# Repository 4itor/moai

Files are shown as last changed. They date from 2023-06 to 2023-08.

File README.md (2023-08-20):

# moai Keyboard

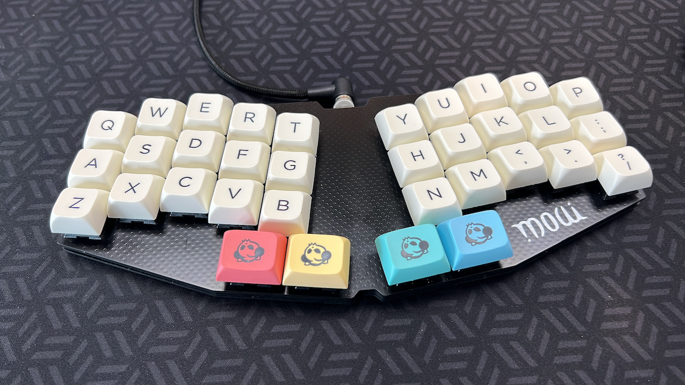
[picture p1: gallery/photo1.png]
Moai


A small, 34 key, low(ish) profile keyboard with MX switches.

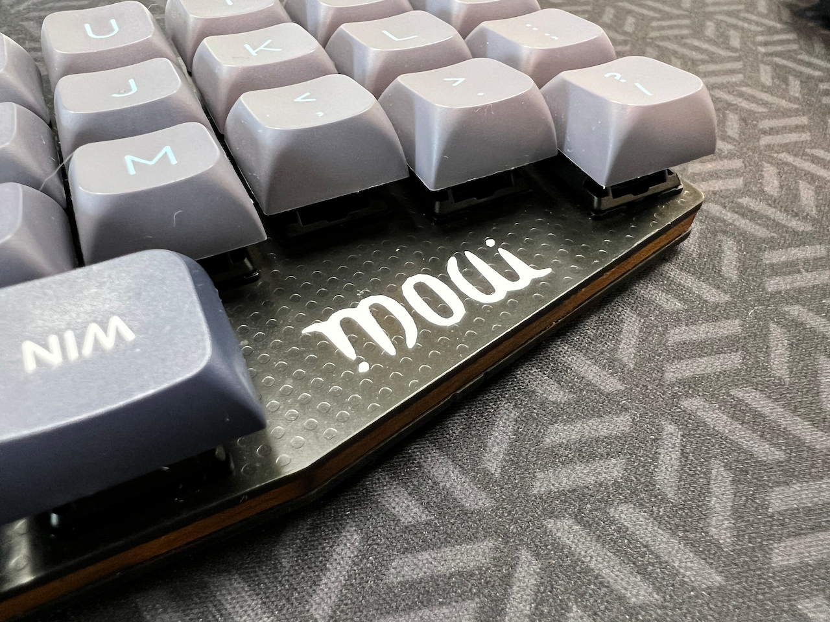
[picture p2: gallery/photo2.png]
Moai Detail


The keyboard is caseless, using just the plate and the pcb, with a maple woodcut (3.3mm height) between both. No screws, the soldered switches keep everything in place.

The wood gives enough stability and it's quite sturdy compared to other caseless builds I've done before (even the ones that used screws).

The texture on top of the plate is created poking holes on the `Cu` layer below; tried just this once and results where better than expected; As the plate is simmetrical I created two designs (one on each side), but only used the textured one for now.

> **Word of advice** : The distance between each pair of thumb keys is tenths of a millimeter less than the standard for 1.25U keys, this is intentional. I have found no incompatibilities in any keycap profiles thrown at it (Cherry, MDA/XVX, XDA, SDA, MT3, etc) from several vendors, but your milleage may vary.

See more pictures in the [Gallery](gallery/README.md).

## About moai

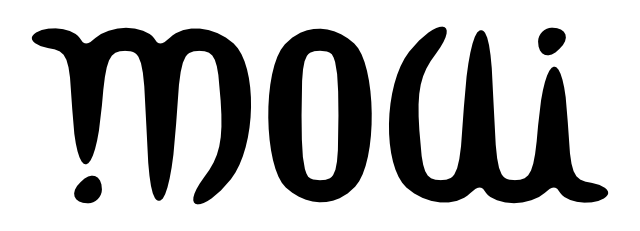
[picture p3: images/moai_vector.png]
Moai Logo


The moai logo is an [ambigram](https://en.wikipedia.org/wiki/Ambigram) on the romanized japanese term `moai`.

Moais (模合, Mo-ai) are social support groups that form in order to provide varying support from social, financial, health, or spiritual interests.

Moai means "meeting for a common purpose" in Japanese and originated from the social support groups in Okinawa, Japan.

Source: [Wikipedia](https://en.wikipedia.org/wiki/Moai_(social_support_groups))

## Design

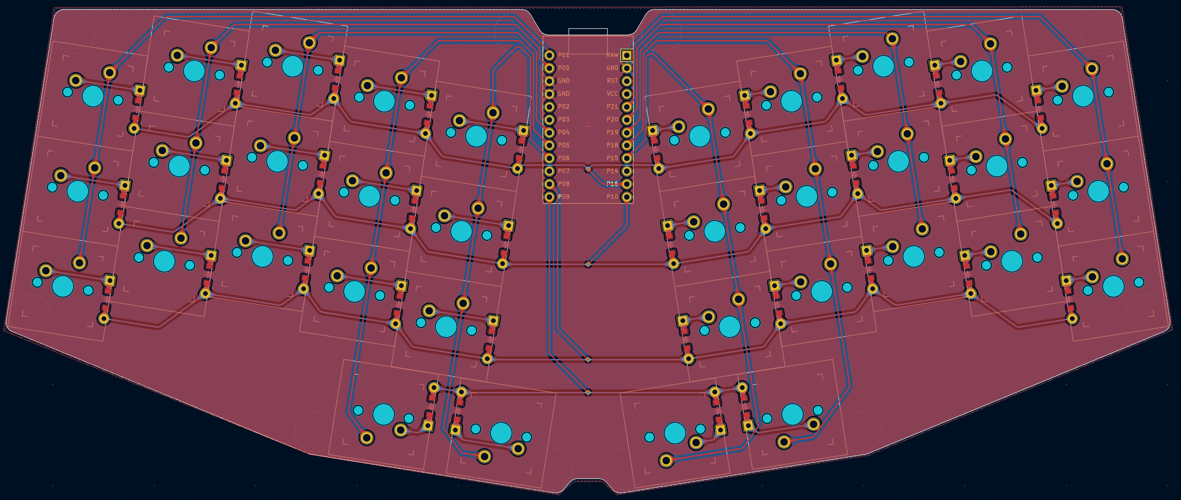
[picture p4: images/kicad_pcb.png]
Moai PCB


It was designed using Ergogen and Kicad.

Original procedural design on [Ergogen](ergogen/moai.yaml) folder and Kicad+Gerbers on [Build Files](build_files/)

## Build

See [build notes](BUILD.md)

## Other Channels

* [Discord](https://discord.com/channels/714176584269168732/1127694421861871636)

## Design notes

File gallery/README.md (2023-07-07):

# Gallery

Moai
Moai

---

Detail
Detail

---

Front
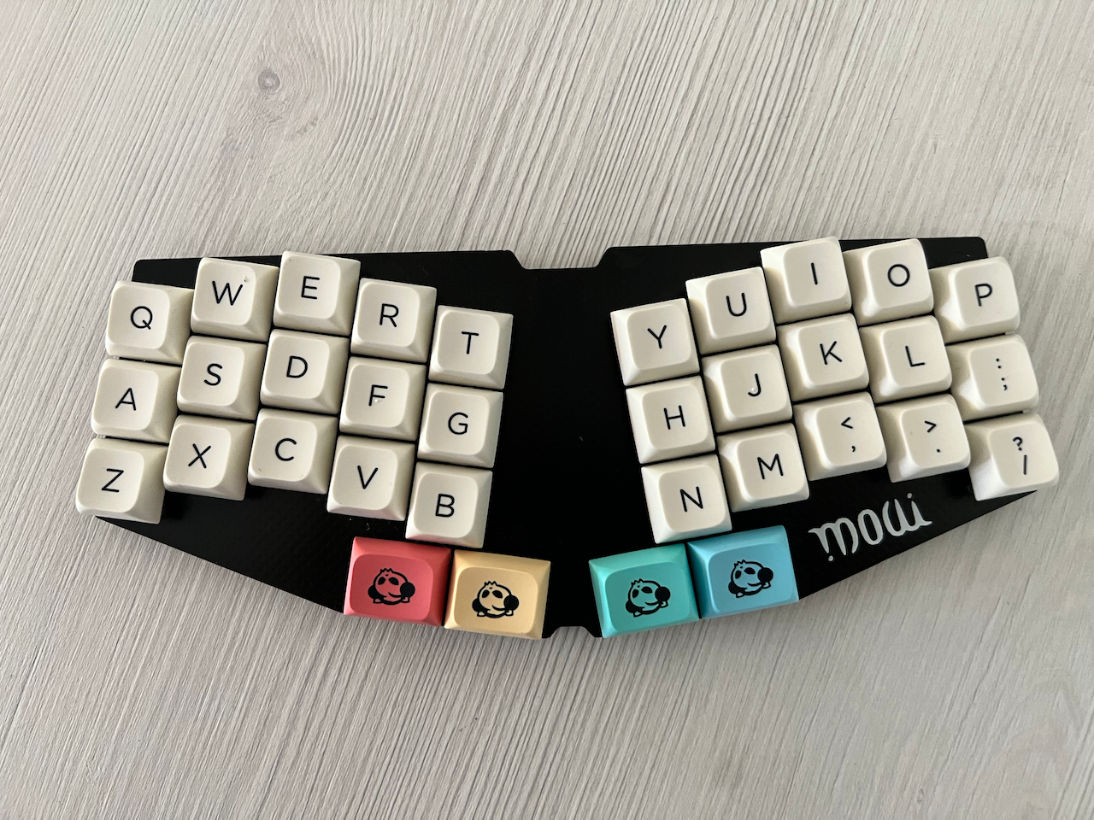
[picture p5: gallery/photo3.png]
Front


---

Back
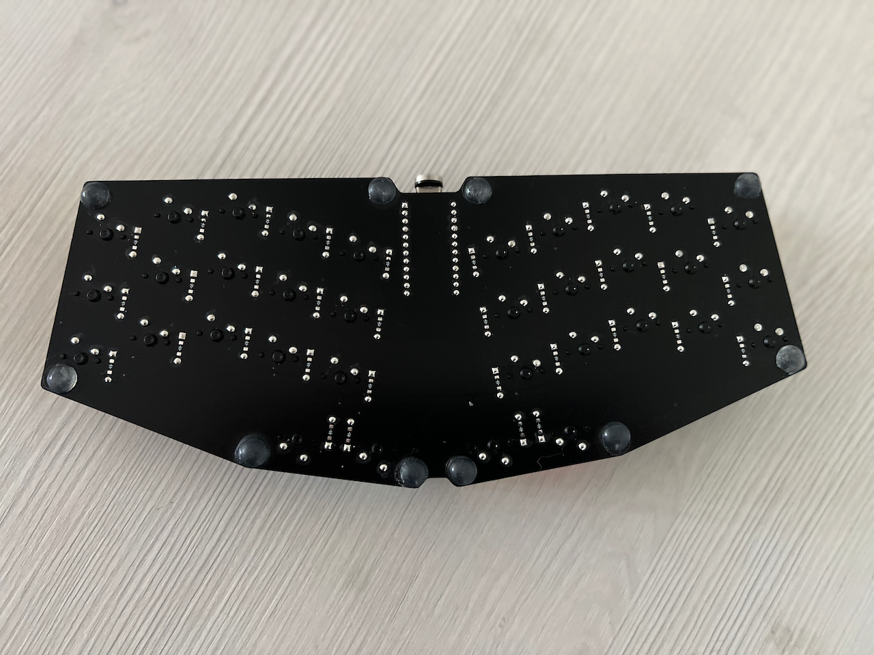
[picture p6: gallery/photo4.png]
Back


---

Work and home drivers.
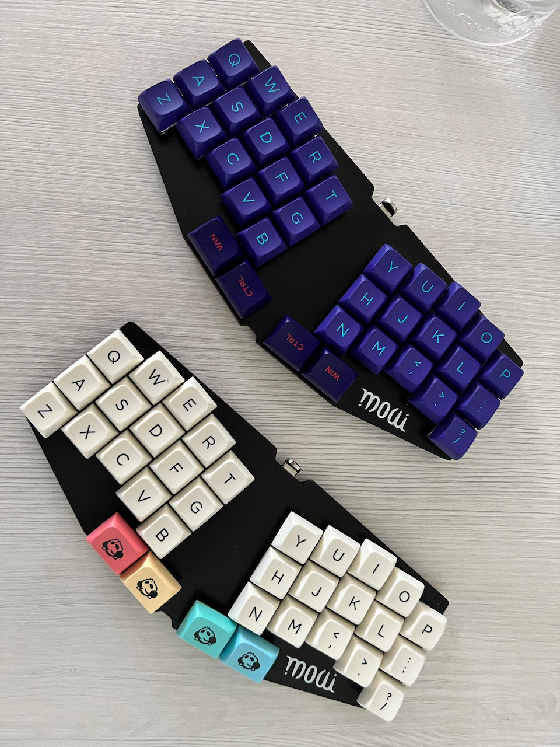
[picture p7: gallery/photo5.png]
Couple


---

Detail of the controller positioning.
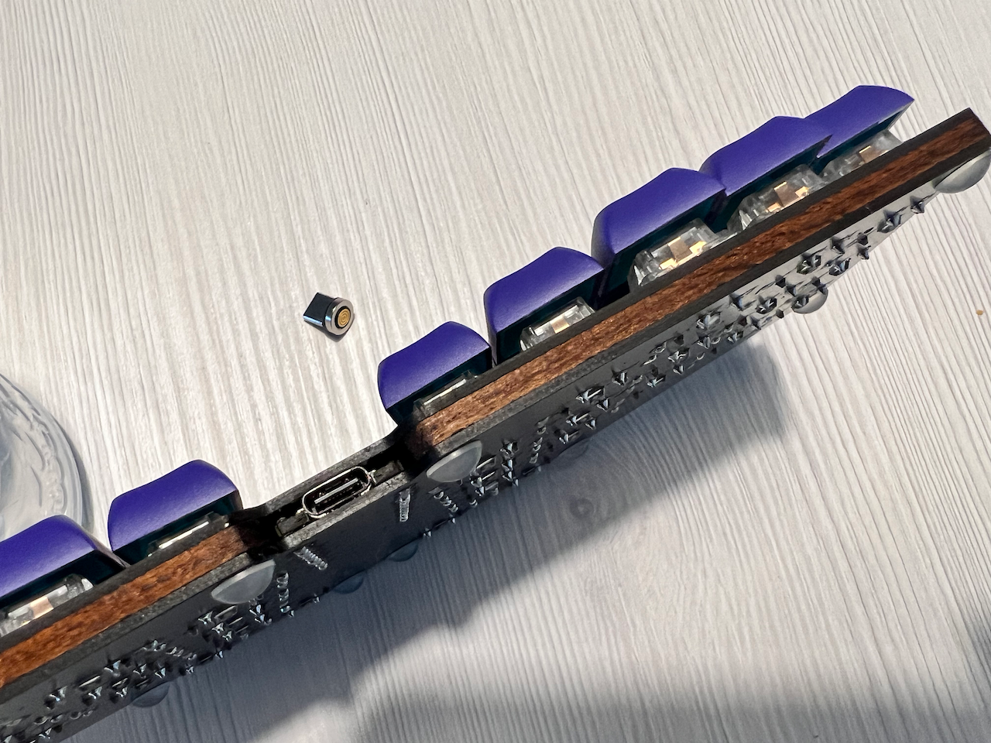
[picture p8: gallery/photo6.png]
Controller


---

Detail of the flush-clipped switch pins after soldering.
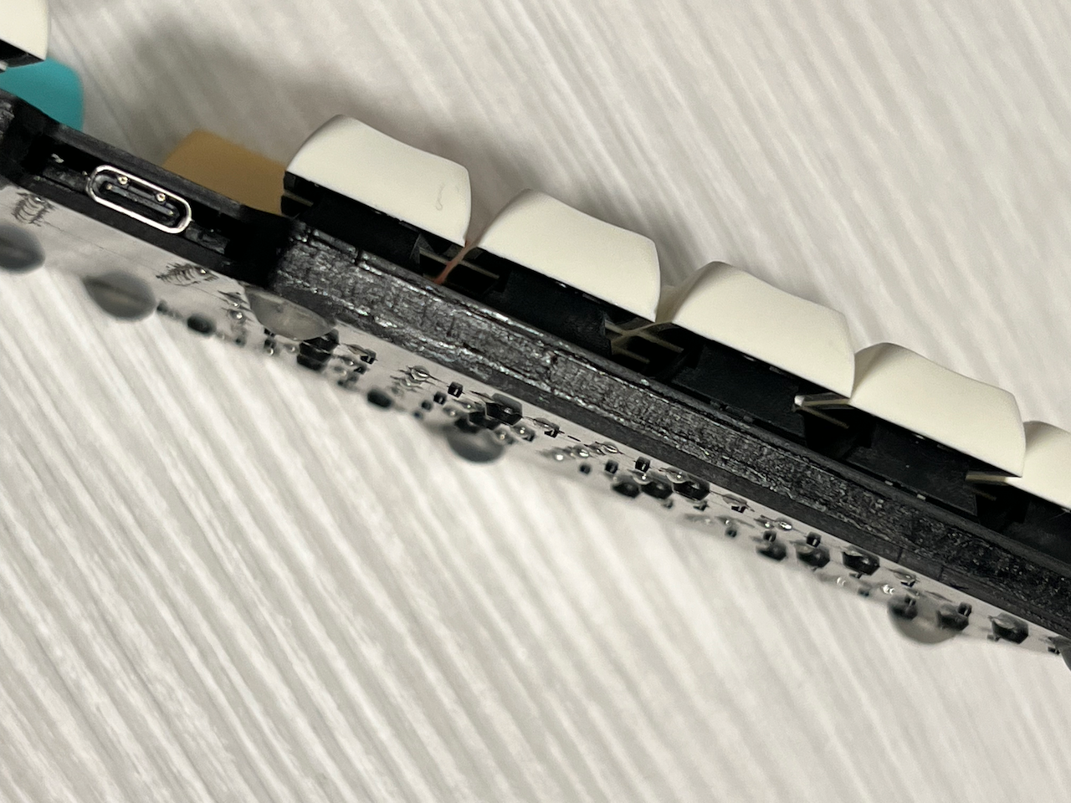
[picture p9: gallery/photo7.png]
ClippedSwitch


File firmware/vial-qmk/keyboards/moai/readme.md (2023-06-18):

# moai

moai

*A short description of the keyboard/project*

* Keyboard Maintainer: [4itor](https://github.com/4itor)
* Hardware Supported: *The PCBs, controllers supported*
* Hardware Availability: *Links to where you can find this hardware*

Make example for this keyboard (after setting up your build environment):

    make moai:default

Flashing example for this keyboard:

    make moai:default:flash

See the [build environment setup](https://docs.qmk.fm/#/getting_started_build_tools) and the [make instructions](https://docs.qmk.fm/#/getting_started_make_guide) for more information. Brand new to QMK? Start with our [Complete Newbs Guide](https://docs.qmk.fm/#/newbs).

## Bootloader

Enter the bootloader in 3 ways:

* **Bootmagic reset**: Hold down the key at (0,0) in the matrix (usually the top left key or Escape) and plug in the keyboard
* **Physical reset button**: Briefly press the button on the back of the PCB - some may have pads you must short instead
* **Keycode in layout**: Press the key mapped to `QK_BOOT` if it is available

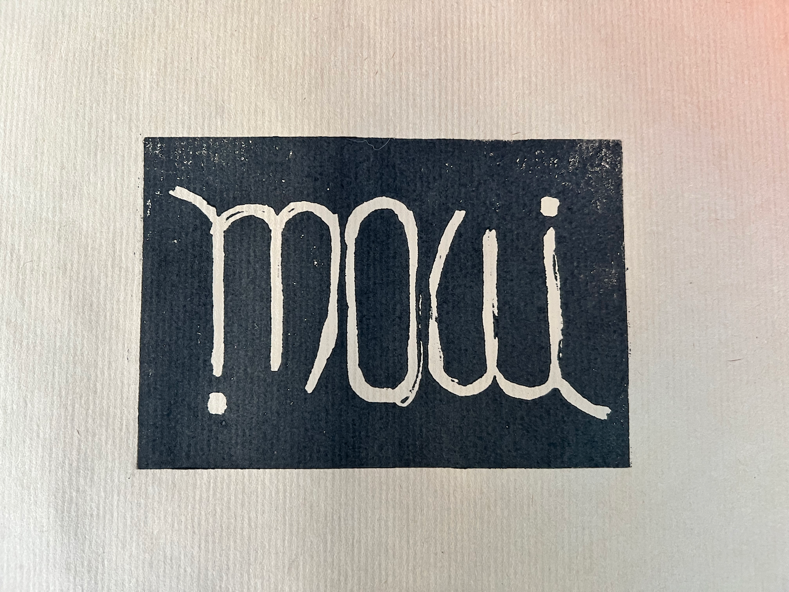
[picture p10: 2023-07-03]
images/moai_lythograph.png

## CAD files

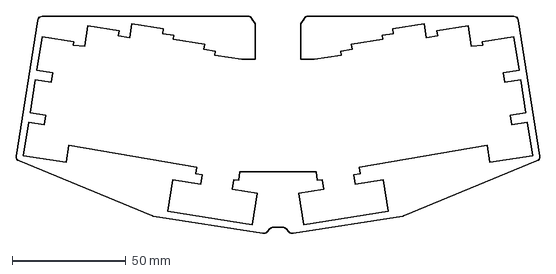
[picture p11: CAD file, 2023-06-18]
build_files/middle_layer.dxf
230.0 x 95.5 mm

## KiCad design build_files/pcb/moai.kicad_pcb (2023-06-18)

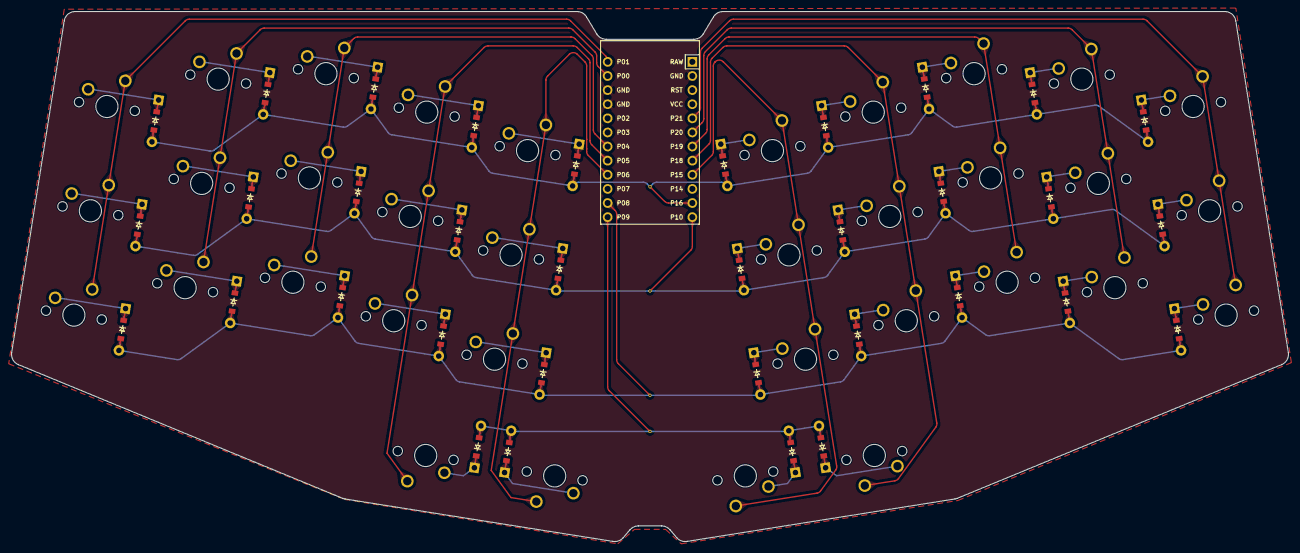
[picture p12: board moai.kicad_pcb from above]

Board: 2 copper layers, 229.8 x 95.4 mm, 69 parts (0 on the bottom side), 49 nets.

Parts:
10.001251, 10.001252, 10.001253, 10.001254, 10.001255, 10.001256, 10.001257, 10.001258, 10.001259, 10.0012510, 10.0012511, 10.0012512, 10.0012513, 10.0012514, 10.0012515, 10.0012516, 10.0012517, 10.0012518, 10.0012519, 10.0012520, 10.0012521, 10.0012522, 10.0012523, 10.0012524, 10.0012525, 10.0012526, 10.0012527, 10.0012528, 10.0012529, 10.0012530, 10.0012531, 10.0012532, 10.0012533, 10.0012534: MX
D1, D2, D3, D4, D5, D6, D7, D8, D9, D10, D11, D12, D13, D14, D15, D16, D17, D18, D19, D20, D21, D22, D23, D24, D25, D26, D27, D28, D29, D30, D31, D32, D33, D34: ComboDiode
MCU1: ProMicro

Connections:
GND: MCU1.2, MCU1.15, MCU1.16
P0: 10.001254.1, 10.001255.1, 10.001256.1, MCU1.14
P1: 10.001251.1, 10.001252.1, 10.001253.1, MCU1.13
P4: 10.001257.1, 10.001258.1, 10.001259.1, MCU1.19
P5: 10.0012510.1, 10.0012511.1, 10.0012512.1, 10.0012531.1, MCU1.20
P6: 10.0012513.1, 10.0012514.1, 10.0012515.1, 10.0012532.1, MCU1.21
P8: D1.2, D4.2, D7.2, D10.2, D13.2, D16.2, D19.2, D22.2, D25.2, D28.2, MCU1.23
P9: D31.2, D32.2, D33.2, D34.2, MCU1.24
P10: D2.2, D5.2, D8.2, D11.2, D14.2, D17.2, D20.2, D23.2, D26.2, D29.2, MCU1.12
P15: 10.0012528.1, 10.0012529.1, 10.0012530.1, 10.0012534.1, MCU1.9
P16: D3.2, D6.2, D9.2, D12.2, D15.2, D18.2, D21.2, D24.2, D27.2, D30.2, MCU1.11
P18: 10.0012525.1, 10.0012526.1, 10.0012527.1, 10.0012533.1, MCU1.8
P19: 10.0012522.1, 10.0012523.1, 10.0012524.1, MCU1.7
P20: 10.0012519.1, 10.0012520.1, 10.0012521.1, MCU1.6
P21: 10.0012516.1, 10.0012517.1, 10.0012518.1, MCU1.5
index_bottom: 10.0012510.2, D10.1
index_home: 10.0012511.2, D11.1
index_top: 10.0012512.2, D12.1
inner_bottom: 10.0012513.2, D13.1
inner_default: 10.0012532.2, D32.1
inner_home: 10.0012514.2, D14.1
inner_top: 10.0012515.2, D15.1
middle_bottom: 10.001257.2, D7.1
middle_home: 10.001258.2, D8.1
middle_top: 10.001259.2, D9.1
mirror_index_bottom: 10.0012525.2, D25.1
mirror_index_home: 10.0012526.2, D26.1
mirror_index_top: 10.0012527.2, D27.1
mirror_inner_bottom: 10.0012528.2, D28.1
mirror_inner_default: 10.0012534.2, D33.1
mirror_inner_home: 10.0012529.2, D29.1
mirror_inner_top: 10.0012530.2, D30.1
mirror_middle_bottom: 10.0012522.2, D22.1
mirror_middle_home: 10.0012523.2, D23.1
mirror_middle_top: 10.0012524.2, D24.1
mirror_outer_default: 10.0012533.2, D34.1
mirror_pinky_bottom: 10.0012516.2, D16.1
mirror_pinky_home: 10.0012517.2, D17.1
mirror_pinky_top: 10.0012518.2, D18.1
mirror_ring_bottom: 10.0012519.2, D19.1
mirror_ring_home: 10.0012520.2, D20.1
mirror_ring_top: 10.0012521.2, D21.1
outer_default: 10.0012531.2, D31.1
pinky_bottom: 10.001251.2, D1.1
pinky_home: 10.001252.2, D2.1
pinky_top: 10.001253.2, D3.1
ring_bottom: 10.001254.2, D4.1
ring_home: 10.001255.2, D5.1
ring_top: 10.001256.2, D6.1

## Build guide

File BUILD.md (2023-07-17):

# Building a Moai

_(Under construction)_

## Bill of Materials

* 1x Moai PCB (see Kicad file)
* 1x Moai Plate (see Kicad file)
* 1x Wood middle layer
  * Laser-cut from a 3.3mm width panel, see `middle_later.dxf` on `build_files/` folder for the design.
  * Optionally 3mm laser-cut acrylic can be used instead, but the results are not as good (it can move a bit defeating its purpose, and maybe a drop of glue is needed to keep it in place)
* 1x Low profile microcontroller
  * 0xCB Helios, Frood RP2040, Elite-Pi, Elite-C LowProfile, etc. It should be able to be soldered flat on top of the pcb with components up (so no components on the bottom) and height has to be about 3mm.
  * I tried 0xCB, Frood and Elite-Pi and those three worked well.
* 34x 1N4148 Diodes
  * Could be either through hole or SMD as the PCB supports both
* 34x MX compatible switches
* 34x Keycaps
  * 30x 1U Alphas
  * 4x 1.25U Modifiers (Preferably R1 if not flat profile)

## Required Tools

* Soldering Iron + Solder
  * Optionally flux if soldering SMD diodes.
  * Solder pad and some fan and ventilation is recommended. Keep a safe environment when soldering.
* Flush Cutter
* Breadboard (or something similar) to hold the controler and the legs in place for soldering.
* Electronic Heat resitant tape
  * Painter tape will do as well :P

## 1. Preparing PCB and Plate

Using Acrylic ink pen, paint the outer border of the plate and the PCB.

...

## 2. Soldering the Diodes

The PCB supports both through the hole or smd diodes, and both abobe and below the PCB.

Keep in mind that the PCB is bare from below, so maybe better to solder the diodes above the pcb instead of below.

Please also take special care in the orientation of the soldered diodes, the 4 thumb keys have them reversed compared to the rest of the keys.

### 2.1 Trough Hole diodes

If using trough hole diodes, use a flush cutter to cut the excess leads. Keep the cutted dioded legs, as they can be used as pins to solder the controller.

### 2.2 SMD diodes

...

## 3. Soldering the Controller

Using a BreadBoard (or similar) solder the diodes's cutted legs on the controller (need to show pictures on how to do this), if using SMD diodes solder pins must be used.

Once all controller pins have soldered legs, put it on top of the pcb with the soldered diode leds inside the pcb controller holes (flush over its surface). Use tape to hold it in place.

Turn the PCB upside down and cut the legs with the flush cutter, the solder it in place and remove the tape.

...

## 4. Soldering the switches

...

> **Optional:** Use also a flush cutter to cut the excess heigh of the pins. I tried and feels amazing once everything is soldered, buuuut it can potentially ruin 34 switches; not recommended for the faint of heart. (You can see the results of this process in the last picture of gallery)

## 5. Keycaps

...

> **Word of advice** : The distance between each pair of thumb keys is tenths of a millimeter less than the standard for 1.25U keys, this is intentional. I have found no incompatibilities in any keycap profiles thrown at it (Cherry, MDA/XVX, XDA, SDA, MT3, etc) from several vendors, but your milleage may vary.

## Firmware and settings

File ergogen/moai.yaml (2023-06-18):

meta:
  engine: 4.0.0
  autor: 4itor
  version: 0.0.2

units:
  # Main layout
  angle: -9
  Distance: 3.25U
  Fillet: 2
  # constants
  S: .525U # Default Spacer
  WS: .70U # Wide Spacer (1.25S)
  TOP: .3U # Top Spacer
  MX: 14 # Size of the MX plate socket

points:
  zones:
    matrix:
      #-- Displacement for KiCad Exports
      anchor:
        shift: [125, -125]
      rotate: angle
      mirror: &mirror
        ref: matrix_inner_bottom
        shift: [0, -U]
        distance: Distance
      columns:
        pinky:
          key:
            col_net: P1
            mirror.col_net: P21
        ring:
          key:
            stagger: 8
            col_net: P0
            mirror.col_net: P20
        middle:
          key:
            stagger: 4
            col_net: P4
            mirror.col_net: P19
        index:
          key:
            stagger: -4
            col_net: P5
            mirror.col_net: P18
        inner:
          key:
            stagger: -4
            col_net: P6
            mirror.col_net: P15
      rows:
        bottom:
          row_net: P8
        home:
          row_net: P10
        top:
          row_net: P16
    thumb:
      mirror: *mirror
      anchor:
        ref: matrix_inner_bottom
        shift: [-.5U, -U]
        rotate: 0
      columns:
        outer:
          key:
            width: 1.25cx
            row_net: P9
            col_net: P5
            mirror.col_net: P18
            rotate: 180 # Inverted switch
        inner:
          key:
            shift: [.25cx, 0]
            width: 1.25cx
            row_net: P9
            col_net: P6
            mirror.col_net: P15
            rotate: 180 # Inverted switch
outlines:
  keys:
    - what: rectangle
      where: -/thumb/
      bound: false
      size: [cx, cx]
    - what: rectangle
      where: /thumb/
      bound: false
      size: [1.25cx, cx]

  switch:
    - what: rectangle
      where: true
      bound: false
      size: [MX, MX]

  board:
    - what: polygon
      operation: stack
      points:
        - ref: matrix_pinky_top
          shift: [-S, +S+TOP]
        - ref: matrix_pinky_bottom
          shift: [-S, -S]
        - ref: thumb_outer
          shift: [WS, S]
        - ref: thumb_inner
          shift: [-WS, S]
        # lower dent
        - aggregate.parts:
            - thumb_inner
            - mirror_thumb_inner
          shift: [-3, -9]
        - shift: [6,0]
        - ref: mirror_thumb_inner
          shift: [-WS, S]
        - ref: mirror_thumb_outer
          shift: [WS, S]
        - ref: mirror_matrix_pinky_bottom
          shift: [-S, -S]
        - ref: mirror_matrix_pinky_top
          shift: [-S, +S+TOP]
        # upper dent (averagind both top corners)
        - aggregate.parts:
          - ref: matrix_pinky_top
            shift: [-S, +S+TOP]
          - ref: mirror_matrix_pinky_top
            shift: [-S, +S+TOP]
          shift: [+12, 0]
        - shift: [-3, -5]
        - shift: [-18, 0]
        - shift: [-3, 5]
      fillet: Fillet

  mcu_slot:
    - what: rectangle
      size: [20, 40]
      corner: 1
      where:
          aggregate.parts:
            - ref: matrix_inner_top
            - ref: mirror_matrix_inner_top
          shift: [0, 5]

  diode_slots:
    - what: rectangle
      size: [MX+5,MX-1.5]
      where: -/thumb/
      adjust:
        shift: [2.5,-1.5]
    - what: rectangle
      size: [MX,MX+5]
      where: /thumb_inner/
      adjust:
        shift: [11,-2.5]

  matrix_hole:
    - what: polygon
      operation: stack
      points:
        - ref: matrix_pinky_top
          shift: [0,5]
        - ref: matrix_pinky_bottom
        - ref: matrix_inner_bottom
          shift: [5,-5]
        - ref: mirror_matrix_inner_bottom
          shift: [5,-5]
        - ref: mirror_matrix_pinky_bottom
        - ref: mirror_matrix_pinky_top
          shift: [0,5]
        - ref: mirror_matrix_inner_top
          shift: [5,7]
        - ref: matrix_inner_top
          shift: [5,7]

  #batt_slot:
  #  - what: rectangle
  #    size: [30, 33] # LP302730
  #    #size: [32, 25] # LP322431
  #    #size: [32, 22] # LP352131
  #    corner: 1
  #    where:
  #        aggregate.parts:
  #          - ref: matrix_inner_top
  #          - ref: mirror_matrix_inner_top
  #        shift: [0, -33]

  plate:
    - name: board
    - operation: subtract
      name: switch

  middle_layer:
    - name: board
    - operation: subtract
      name: switch
    - operation: subtract
      name: mcu_slot
    - operation: subtract
      name: diode_slots
    - operation: subtract
      name: matrix_hole
    #- operation: subtract
    #  name: batt_slot
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

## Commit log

2023-06-18 Init files
    [middle_layer.dxf, moai-plate.kicad_pcb, moai.kicad_pcb]
2023-07-07 Switch pin clipping example.
2023-10-31 Gerber Files for Pcb/Plate manufacturing
2023-11-01 Plate Gerbers
    [moai-plate.kicad_pcb]
